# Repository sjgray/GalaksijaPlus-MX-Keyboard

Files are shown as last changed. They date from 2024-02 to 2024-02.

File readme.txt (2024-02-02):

Galaksija Plus MX Keyboard   (C)2024 Steve J. Gray
==========================   www.sjgray.ca

"GAL-V1-R1"

This is an MX keyboard for the Galaksija Plus computer.
It uses a 6.25u spacebar and is close to, but modified
compared to the standard layout in order to use modern
PC-type MX keycaps.

Included are the Kicad 7 design files.
Gerbers are included that can be sent to the board
house.

Steve

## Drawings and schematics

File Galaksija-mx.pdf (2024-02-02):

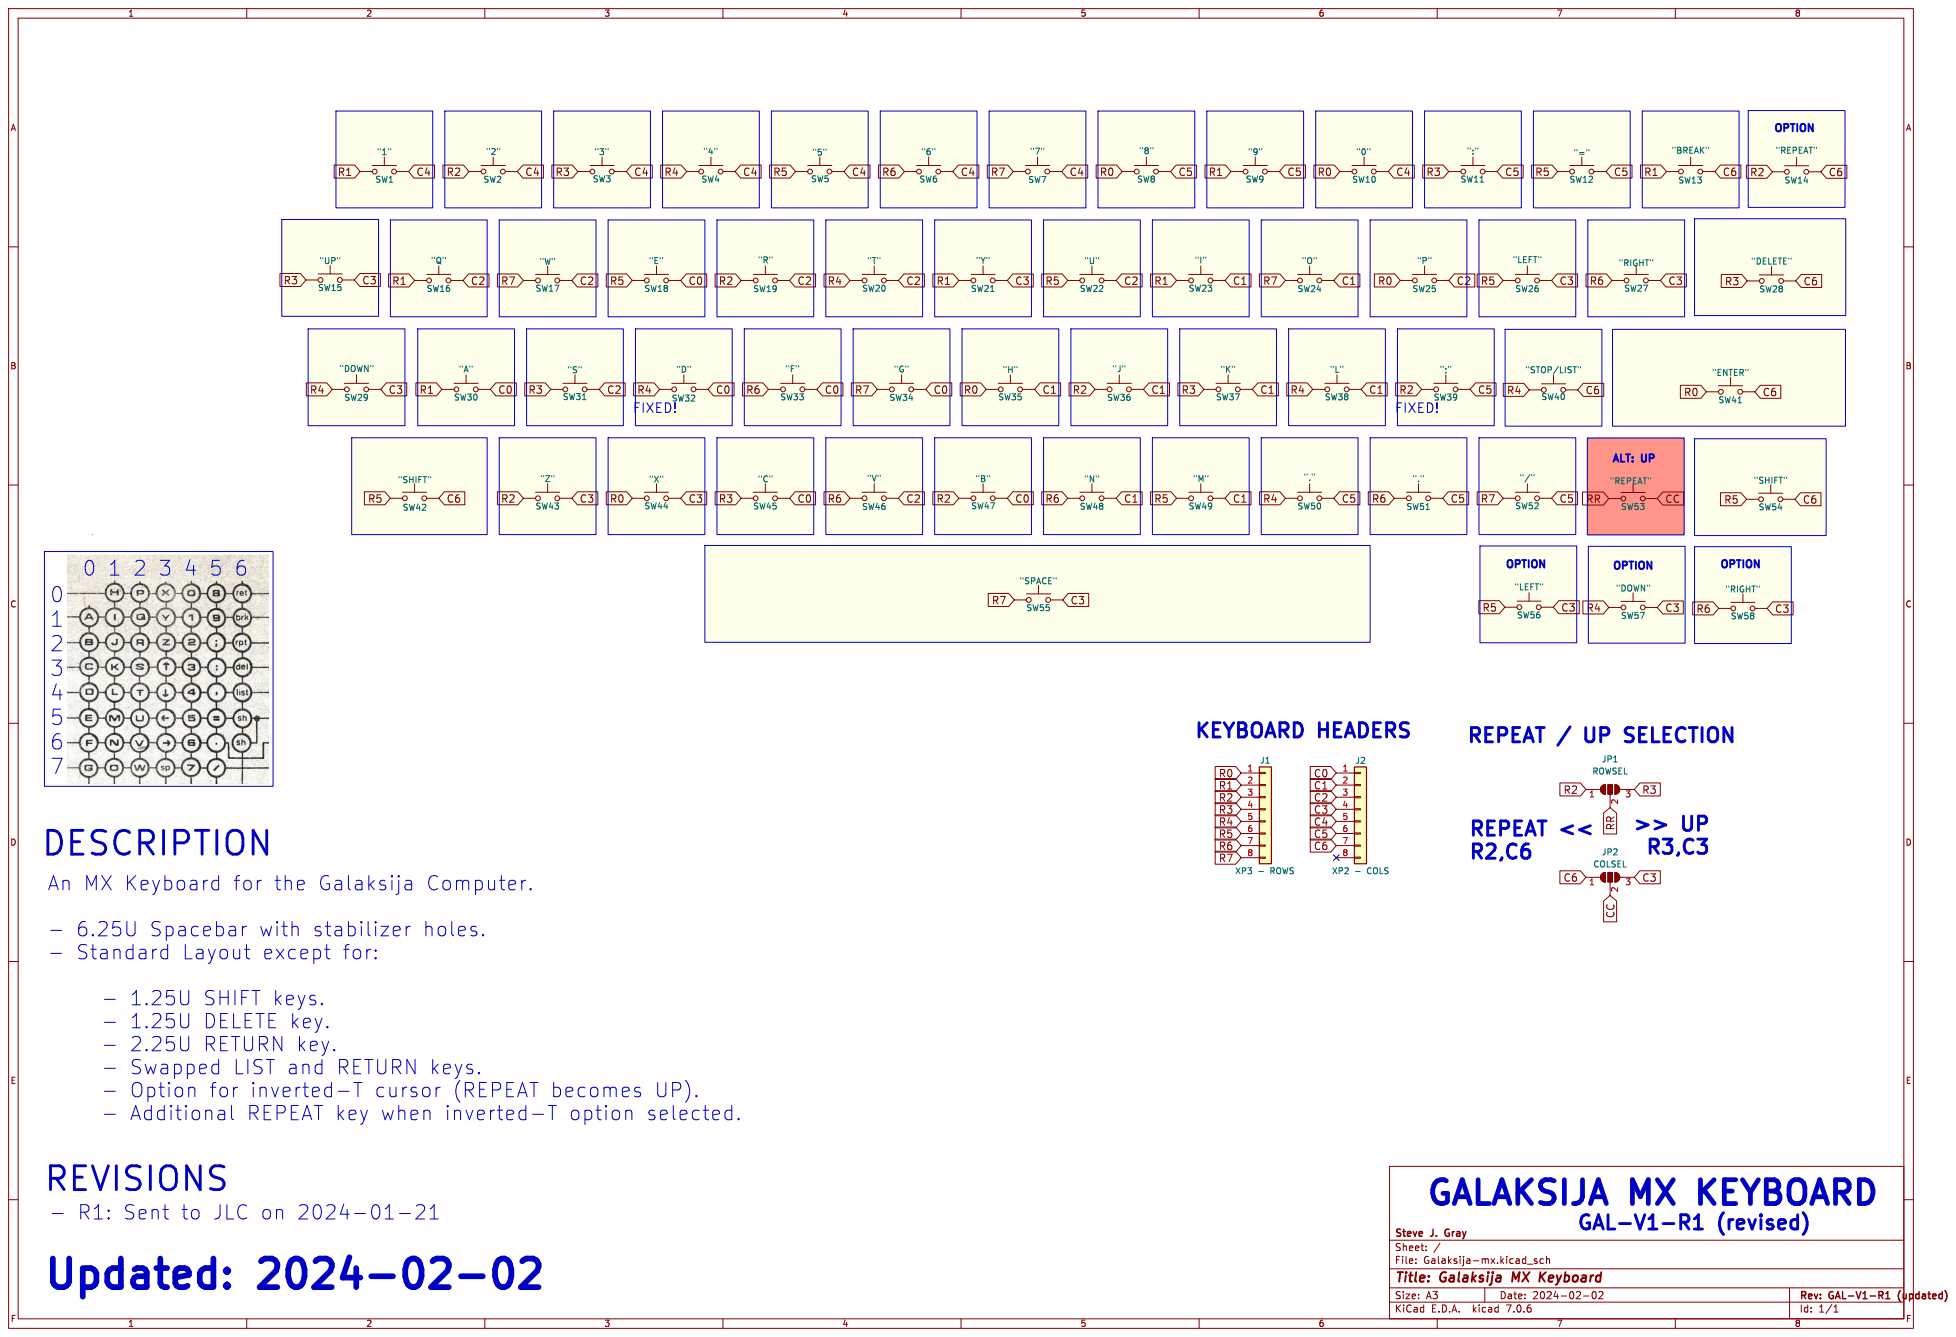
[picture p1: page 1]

REVISIONS
- R1: Sent to JLC on 2024-01-21
Updated: 2024-02-02

File: Galaksija-mx.kicad_sch Sheet: / Steve J. Gray

Id: 1/1 Title: Galaksija MX Keyboard

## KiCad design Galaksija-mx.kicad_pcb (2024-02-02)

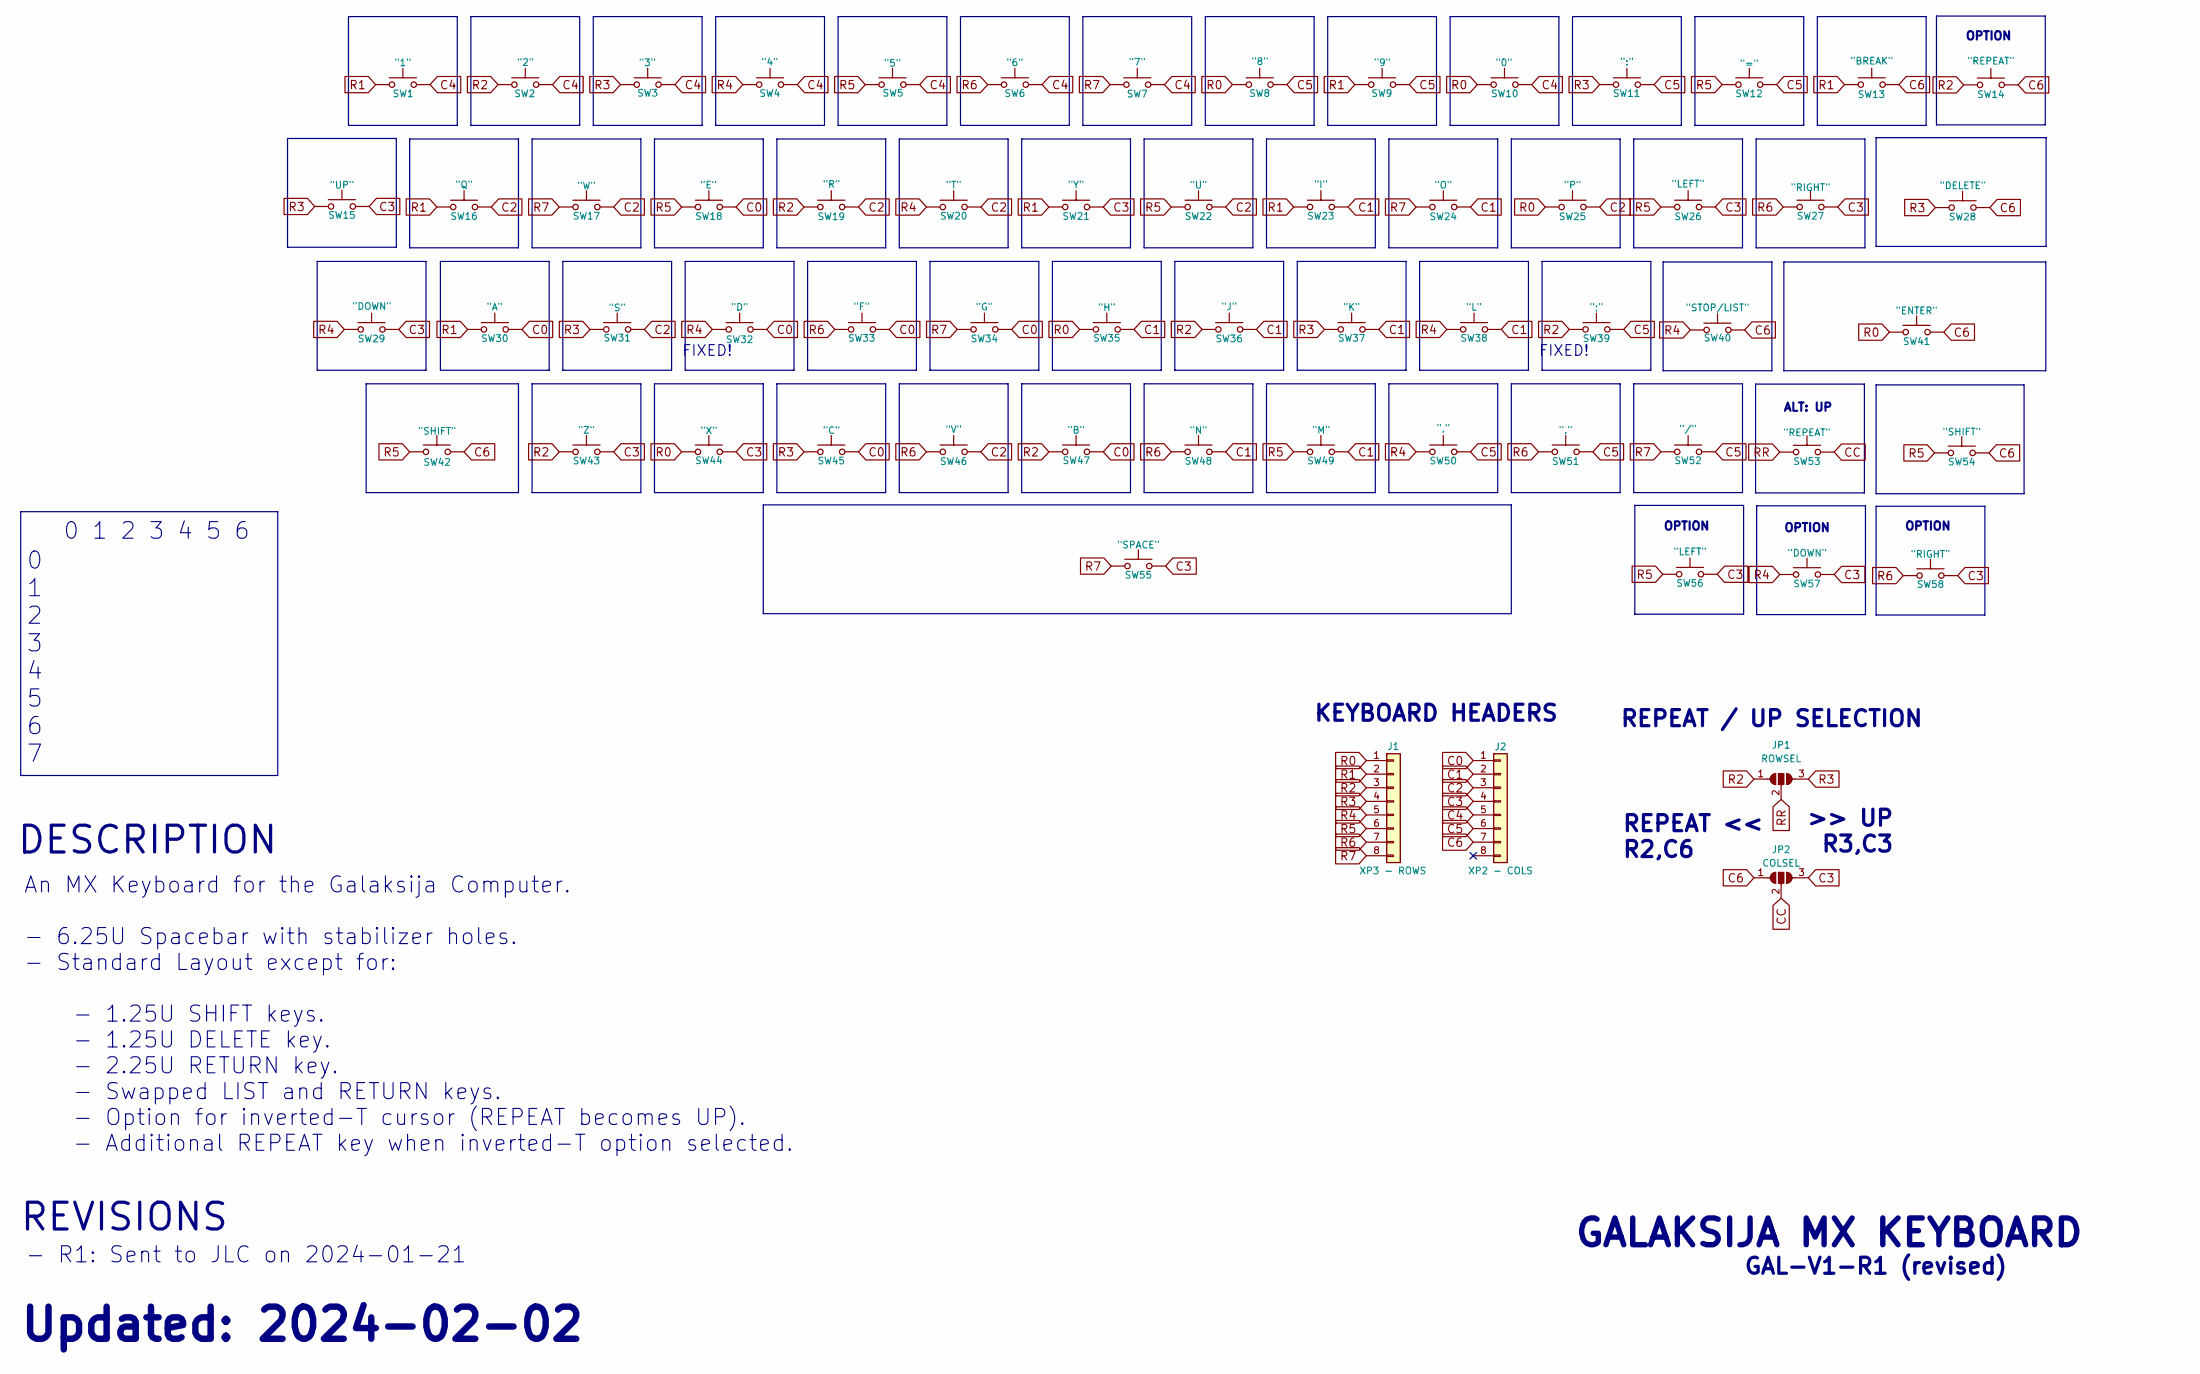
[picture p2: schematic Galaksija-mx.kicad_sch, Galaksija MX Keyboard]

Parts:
J1: XP3 - ROWS; PinHeader_1x08_P2.54mm_Vertical
J2: XP2 - COLS; PinHeader_1x08_P2.54mm_Vertical
JP1: ROWSEL; SolderJumper-3_P1.3mm_Open_RoundedPad1.0x1.5mm_NumberLabels
JP2: COLSEL; SolderJumper-3_P1.3mm_Open_RoundedPad1.0x1.5mm_NumberLabels
SW1: "1"; SW_Hybrid_CherryMX_GateronLP_1.00u_PCB
SW2: "2"; SW_Hybrid_CherryMX_GateronLP_1.00u_PCB
SW3: "3"; SW_Hybrid_CherryMX_GateronLP_1.00u_PCB
SW4: "4"; SW_Hybrid_CherryMX_GateronLP_1.00u_PCB
SW5: "5"; SW_Hybrid_CherryMX_GateronLP_1.00u_PCB
SW6: "6"; SW_Hybrid_CherryMX_GateronLP_1.00u_PCB
SW7: "7"; SW_Hybrid_CherryMX_GateronLP_1.00u_PCB
SW8: "8"; SW_Hybrid_CherryMX_GateronLP_1.00u_PCB
SW9: "9"; SW_Hybrid_CherryMX_GateronLP_1.00u_PCB
SW10: "0"; SW_Hybrid_CherryMX_GateronLP_1.00u_PCB
SW11: ":"; SW_Hybrid_CherryMX_GateronLP_1.00u_PCB
SW12: "="; SW_Hybrid_CherryMX_GateronLP_1.00u_PCB
SW13: "BREAK"; SW_Hybrid_CherryMX_GateronLP_1.00u_PCB
SW14, SW53: "REPEAT"; SW_Hybrid_CherryMX_GateronLP_1.00u_PCB
SW15: "UP"; SW_Hybrid_CherryMX_GateronLP_1.00u_PCB
SW16: "Q"; SW_Hybrid_CherryMX_GateronLP_1.00u_PCB
SW17: "W"; SW_Hybrid_CherryMX_GateronLP_1.00u_PCB
SW18: "E"; SW_Hybrid_CherryMX_GateronLP_1.00u_PCB
SW19: "R"; SW_Hybrid_CherryMX_GateronLP_1.00u_PCB
SW20: "T"; SW_Hybrid_CherryMX_GateronLP_1.00u_PCB
SW21: "Y"; SW_Hybrid_CherryMX_GateronLP_1.00u_PCB
SW22: "U"; SW_Hybrid_CherryMX_GateronLP_1.00u_PCB
SW23: "I"; SW_Hybrid_CherryMX_GateronLP_1.00u_PCB
SW24: "O"; SW_Hybrid_CherryMX_GateronLP_1.00u_PCB
SW25: "P"; SW_Hybrid_CherryMX_GateronLP_1.00u_PCB
SW26, SW56: "LEFT"; SW_Hybrid_CherryMX_GateronLP_1.00u_PCB
SW27, SW58: "RIGHT"; SW_Hybrid_CherryMX_GateronLP_1.00u_PCB
SW28: "DELETE"; SW_Hybrid_CherryMX_GateronLP_1.50u_PCB
SW29, SW57: "DOWN"; SW_Hybrid_CherryMX_GateronLP_1.00u_PCB
SW30: "A"; SW_Hybrid_CherryMX_GateronLP_1.00u_PCB
SW31: "S"; SW_Hybrid_CherryMX_GateronLP_1.00u_PCB
SW32: "D"; SW_Hybrid_CherryMX_GateronLP_1.00u_PCB
SW33: "F"; SW_Hybrid_CherryMX_GateronLP_1.00u_PCB
SW34: "G"; SW_Hybrid_CherryMX_GateronLP_1.00u_PCB
SW35: "H"; SW_Hybrid_CherryMX_GateronLP_1.00u_PCB
SW36: "J"; SW_Hybrid_CherryMX_GateronLP_1.00u_PCB
SW37: "K"; SW_Hybrid_CherryMX_GateronLP_1.00u_PCB
SW38: "L"; SW_Hybrid_CherryMX_GateronLP_1.00u_PCB
SW39: ";"; SW_Hybrid_CherryMX_GateronLP_1.00u_PCB
SW40: "STOP/LIST"; SW_Hybrid_CherryMX_GateronLP_1.00u_PCB
SW41: "ENTER"; SW_Hybrid_CherryMX_GateronLP_2.25u_PCB
SW42, SW54: "SHIFT"; SW_Hybrid_CherryMX_GateronLP_1.25u_PCB
SW43: "Z"; SW_Hybrid_CherryMX_GateronLP_1.00u_PCB
SW44: "X"; SW_Hybrid_CherryMX_GateronLP_1.00u_PCB
SW45: "C"; SW_Hybrid_CherryMX_GateronLP_1.00u_PCB
SW46: "V"; SW_Hybrid_CherryMX_GateronLP_1.00u_PCB
SW47: "B"; SW_Hybrid_CherryMX_GateronLP_1.00u_PCB
SW48: "N"; SW_Hybrid_CherryMX_GateronLP_1.00u_PCB
SW49: "M"; SW_Hybrid_CherryMX_GateronLP_1.00u_PCB
SW50: ","; SW_Hybrid_CherryMX_GateronLP_1.00u_PCB
SW51: "."; SW_Hybrid_CherryMX_GateronLP_1.00u_PCB
SW52: "/"; SW_Hybrid_CherryMX_GateronLP_1.00u_PCB
SW55: "SPACE"; SW_Hybrid_CherryMX_GateronLP_6.25u_PCB

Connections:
C0: J2.1, SW18.2, SW30.2, SW32.2, SW33.2, SW34.2, SW45.2, SW47.2
C1: J2.2, SW23.2, SW24.2, SW35.2, SW36.2, SW37.2, SW38.2, SW48.2, SW49.2
C2: J2.3, SW16.2, SW17.2, SW19.2, SW20.2, SW22.2, SW25.2, SW31.2, SW46.2
C3: J2.4, JP2.3 (B), SW15.2, SW21.2, SW26.2, SW27.2, SW29.2, SW43.2, SW44.2, SW55.2, SW56.2, SW57.2, SW58.2
C4: J2.5, SW1.2, SW2.2, SW3.2, SW4.2, SW5.2, SW6.2, SW7.2, SW10.2
C5: J2.6, SW8.2, SW9.2, SW11.2, SW12.2, SW39.2, SW50.2, SW51.2, SW52.2
C6: J2.7, JP2.1 (A), SW13.2, SW14.2, SW28.2, SW40.2, SW41.2, SW42.2, SW54.2
CC: JP2.2 (C), SW53.2
R0: J1.1, SW8.1, SW10.1, SW25.1, SW35.1, SW41.1, SW44.1
R1: J1.2, SW1.1, SW9.1, SW13.1, SW16.1, SW21.1, SW23.1, SW30.1
R2: J1.3, JP1.1 (A), SW2.1, SW14.1, SW19.1, SW36.1, SW39.1, SW43.1, SW47.1
R3: J1.4, JP1.3 (B), SW3.1, SW11.1, SW15.1, SW28.1, SW31.1, SW37.1, SW45.1
R4: J1.5, SW4.1, SW20.1, SW29.1, SW32.1, SW38.1, SW40.1, SW50.1, SW57.1
R5: J1.6, SW5.1, SW12.1, SW18.1, SW22.1, SW26.1, SW42.1, SW49.1, SW54.1, SW56.1
R6: J1.7, SW6.1, SW27.1, SW33.1, SW46.1, SW48.1, SW51.1, SW58.1
R7: J1.8, SW7.1, SW17.1, SW24.1, SW34.1, SW52.1, SW55.1
RR: JP1.2 (C), SW53.1

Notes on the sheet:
0 1 2 3 4 5 6
OPTION
0 1 2 3 4 5 6 7
FIXED!
DESCRIPTION
An MX Keyboard for the Galaksija Computer. - 6.25U Spacebar with stabilizer holes. - Standard Layout except for: - 1.25U SHIFT keys. - 1.25U DELETE key. - 2.25U RETURN key. - Swapped LIST and RETURN keys. - Option for inverted-T cursor (REPEAT becomes UP). - Additional REPEAT key when inverted-T op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
GAL-V1-R1 (revised)
REPEAT / UP SELECTION
KEYBOARD HEADERS
GALAKSIJA MX KEYBOARD
>> UP R3,C3
REVISIONS
REPEAT << R2,C6
Updated: 2024-02-02
- R1: Sent to JLC on 2024-01-21
ALT: UP

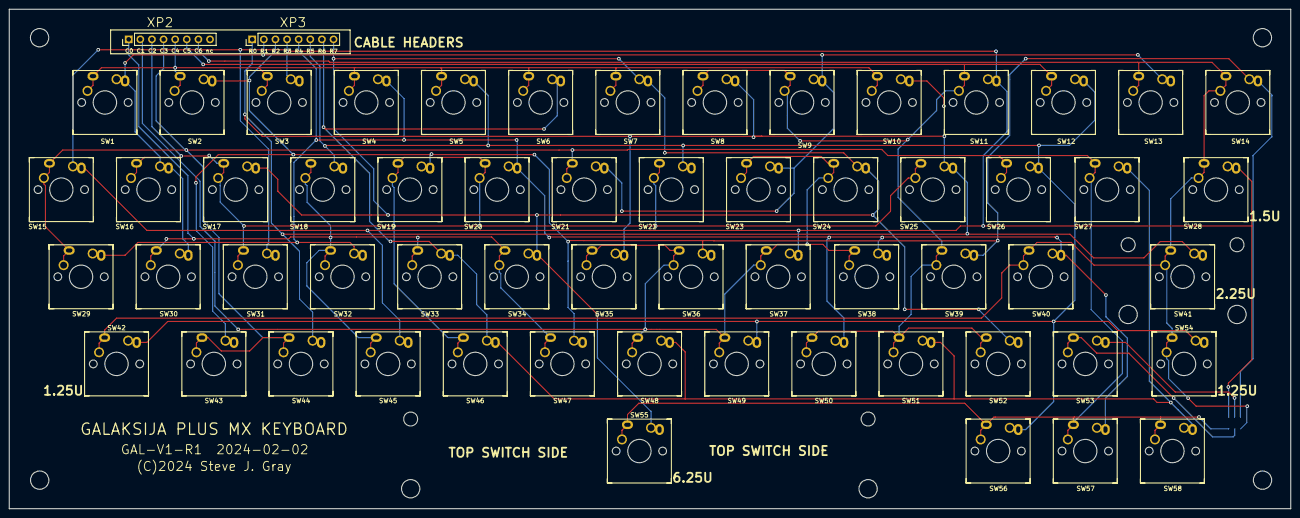
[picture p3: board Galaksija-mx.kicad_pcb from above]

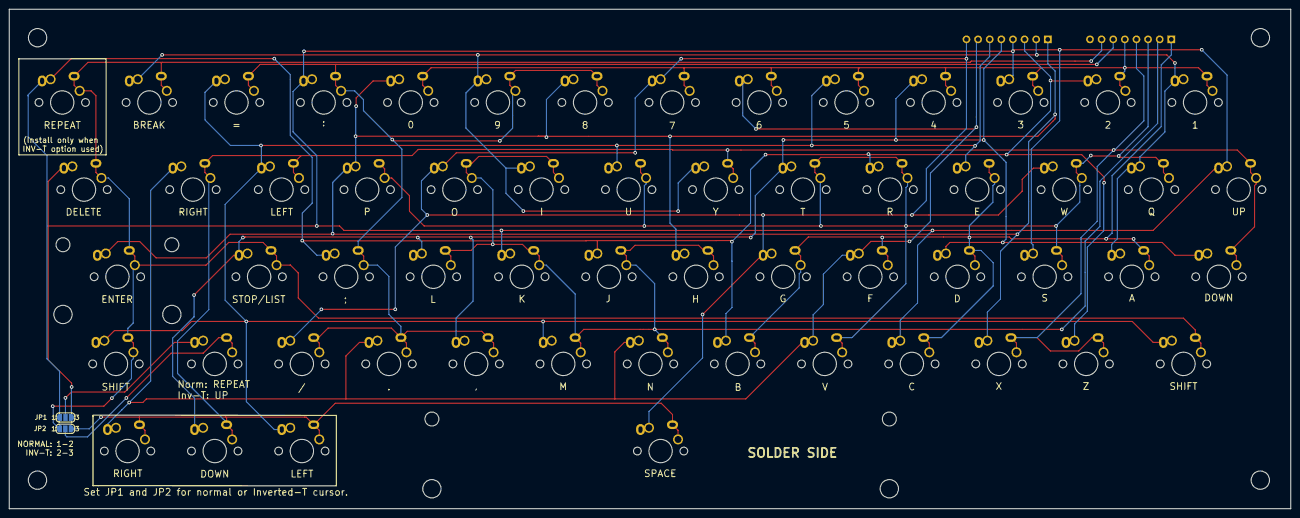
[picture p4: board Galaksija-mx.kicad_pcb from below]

Board: 2 copper layers, 280.1 x 109.2 mm, 62 parts (2 on the bottom side), 17 nets.
